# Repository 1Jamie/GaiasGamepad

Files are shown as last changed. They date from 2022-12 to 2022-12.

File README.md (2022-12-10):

# Gaia's Gampad (GGP)
This is most of what is required to make this gamepad from scratch. This gamepad was made with an arduino micro, 3d printed casing, and handmade circuit boards. Maybe at some point i will do a better writeup of this with detailed instructions on how to make your own. But hey... technically everything is here that you need.

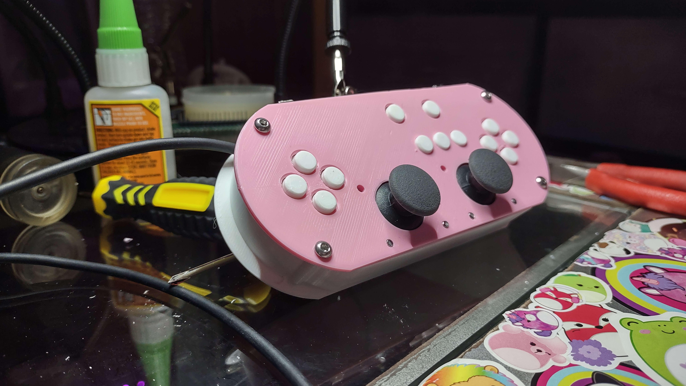
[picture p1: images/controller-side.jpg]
image of controller #2

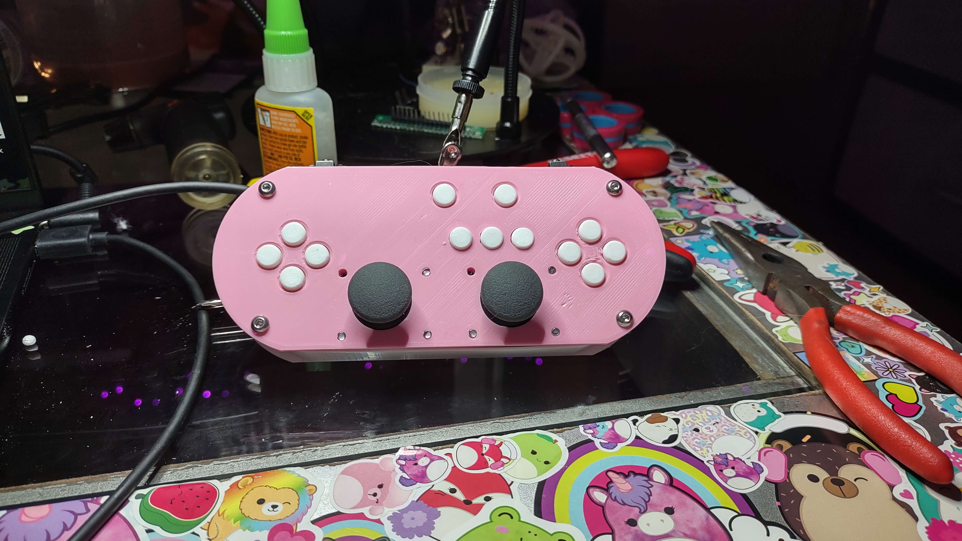
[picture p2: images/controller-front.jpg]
image of controller


## Overview
This controller supports 16 buttons for inputs and one button from swapping mode, current supports mouse input mode and standard HID gamepad input. We are using the gampad library for the micro that can be found in the arduino ide library manager. The buttons themselves are setup using a button matrix scanning through the inputs over and over again every cycle. Also included are the wiring schematics for this gamepad in case you would like to reproduce it or improove it. Please note its only populated with a schematic and not a pcb layout or the like but kiCad auto generates the file for you.

## Parts
- Arduino Micro
- pla casing
- 17 push buttons
- 17 diodes (one per button to prevent ghosting)
- 2 analog sticks with pcb module for them to mount with
- 5 pefboards cut to size
- arduino socket
- m3 screws
- a lot of wire

### more coming eventually
i want a full instruction but dont have the effort right now

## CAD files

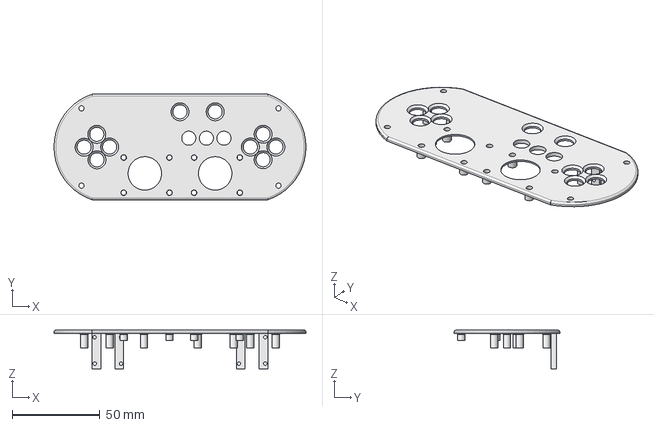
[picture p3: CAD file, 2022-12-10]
ggp-topdeck.FCStd
143.3 x 60.0 x 22.0 mm

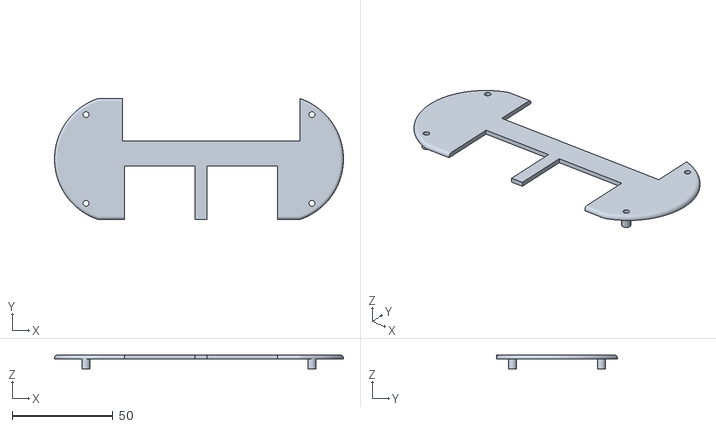
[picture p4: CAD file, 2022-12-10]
stl/ggp-backplate-v1.stl
143.3 x 60.0 x 7.00

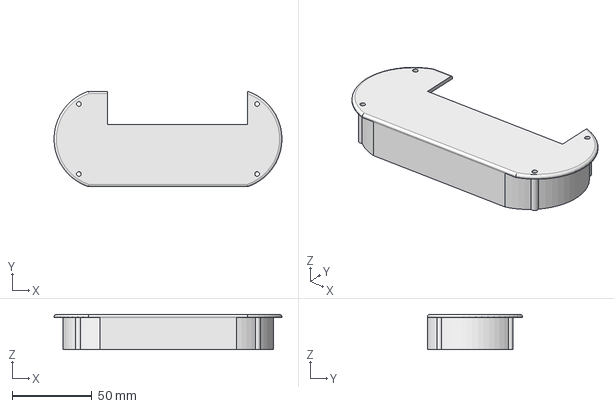
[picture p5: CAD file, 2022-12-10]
ggp-backplate.FCStd
143.3 x 60.0 x 22.0 mm

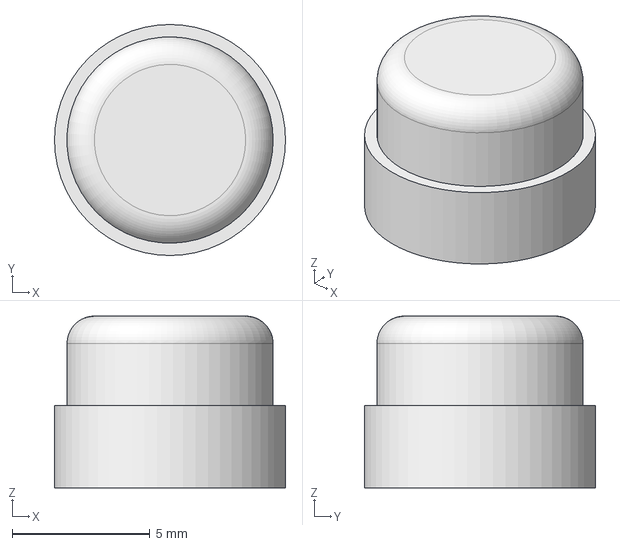
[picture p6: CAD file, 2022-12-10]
ggs-button-caps.FCStd
8.40 x 8.40 x 6.25 mm

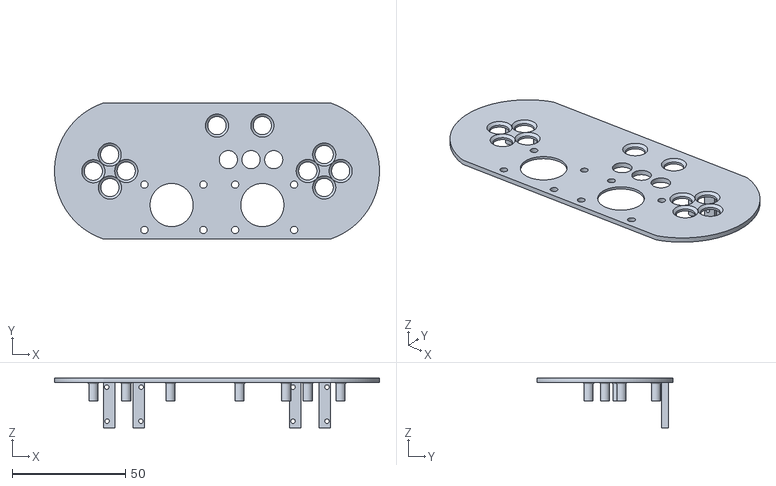
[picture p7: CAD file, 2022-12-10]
stl/ggp-topdeck-v1-3.stl
143.3 x 60.0 x 22.0

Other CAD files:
stl/ggp-topdeck-v1-4.stl
stl/ggp-backplate-v1-1.stl
stl/ggp-button-caps-v1-2.stl

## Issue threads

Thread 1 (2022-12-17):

Enable joystick click

1Jamie, 2022-12-17:
Hardware currently is not wired up for the joystick clicks to work, debating on it as it will take more pins and make analog triggers impossible due to not enough inputs

1Jamie, 2022-12-17:
Also when doing this i need to map the extra center buttons to new things instead of stick clicks.

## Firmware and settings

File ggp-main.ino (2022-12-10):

#include <Joystick.h>
#include <Mouse.h>

// set our pins
int potpinRx = A0;
int potpinRy = A1;
int potpinLx = A2;
int potpinLy = A3;
int modepin = 22;

// set our variables
int mode = 0;
int lastmode = 0;
String pressed;

// setup 4x4 matrix using pins 4-7 and 8-11
char cols[4] = {4, 5, 6, 7};
char rows[4] = {8, 9, 10, 11};
const int colCount = sizeof(cols) / sizeof(cols[0]);
const int rowCount = sizeof(rows) / sizeof(rows[0]);
byte keys[colCount][rowCount];

// function for range mapping
float mapfloat(float x, float in_min, float in_max, float out_min, float out_max)
{
    return (x - in_min) * (out_max - out_min) / (in_max - in_min) + out_min;
}

// setup our joystick
Joystick_ Joystick(JOYSTICK_DEFAULT_REPORT_ID, JOYSTICK_TYPE_GAMEPAD,
                   16, 0,                // Button Count, Hat Switch Count
                   true, true, false,    // X and Y, but no Z Axis
                   true, true, false,    // Rx, Ry, but no Rz
                   false, false,         // No rudder or throttle
                   false, false, false); // No accelerator, brake, or steering

// our setup function
void setup()
{
    // set pin d22 as pullup input
    pinMode(modepin, INPUT_PULLUP);
    // read the mode pin for our initial state
    lastmode = digitalRead(modepin);
    // Initialize Joystick Library
    Joystick.begin();
    Joystick.setXAxisRange(-127, 127);
    Joystick.setYAxisRange(-127, 127);
    Joystick.setRxAxisRange(-127, 127);
    Joystick.setRyAxisRange(-127, 127);

    // initialize the matrix
    for (int i = 0; i < colCount; i++)
    {
        pinMode(cols[i], OUTPUT);
        digitalWrite(cols[i], HIGH);
        Serial.print(cols[i]);
        Serial.print(" ");
    }
    Serial.println();
    for (int i = 0; i < rowCount; i++)
    {
        pinMode(rows[i], INPUT_PULLUP);
        Serial.print(rows[i]);
        Serial.print(" ");
    }
}

// our function to read the matrix
void readMatrix()
{
    // iterate the columns
    for (int colIndex = 0; colIndex < colCount; colIndex++)
    {
        // col: set to output to low
        byte curCol = cols[colIndex];
        pinMode(curCol, OUTPUT);
        digitalWrite(curCol, LOW);

        // row: interate through the rows
        for (int rowIndex = 0; rowIndex < rowCount; rowIndex++)
        {
            byte rowCol = rows[rowIndex];
            pinMode(rowCol, INPUT_PULLUP);
            keys[colIndex][rowIndex] = !digitalRead(rowCol);
            pinMode(rowCol, INPUT);
        }
        // disable the column
        pinMode(curCol, INPUT);
    }
}

// Last state of the buttons
int lastButtonState[16] = {0, 0, 0, 0, 0, 0, 0, 0, 0, 0, 0, 0, 0, 0, 0, 0};

// our main loop
void loop()
{
    // Read the mode pin
    int tmpmode = digitalRead(modepin);
    // if the mode pin has changed then change the mode from 0 to 1 or 1 to 0
    if (tmpmode != lastmode && tmpmode == 0)
    {
        mode = !mode;
        Serial.println(mode);
        lastmode = tmpmode;
        // start up the mouse if 1 and stop it if 0
        if (mode == 1)
        {
            Mouse.begin();
        }
        else if (mode == 0)
        {
            Mouse.end();
        }
    }
    else
    {
        lastmode = tmpmode;
    }

    // use the readMatrix function to read the matrix
    readMatrix();

    // check which mode we are in
    if (mode == 0)
    {
        // Read pin values, map them to the proper range
        int potMappedRx = mapfloat(analogRead(potpinRx), 0, 1023, -127, 127);
        int potMappedRy = mapfloat(analogRead(potpinRy), 0, 1023, -127, 127);
        int potMappedLx = mapfloat(analogRead(potpinLx), 0, 1023, -127, 127);
        int potMappedLy = mapfloat(analogRead(potpinLy), 0, 1023, -127, 127);
        // send the joystick values to the computer
        Joystick.setXAxis(potMappedLx);
        Joystick.setYAxis(potMappedLy);
        Joystick.setRxAxis(potMappedRx);
        Joystick.setRyAxis(potMappedRy);

        // read through keys array by row and see if any buttons have changed state
        for (int i = 0; i < rowCount; i++)
        {
            for (int j = 0; j < colCount; j++)
            {
                int buttonIndex = i * colCount + j;
                int buttonState = keys[j][i];
                // if the button state has changed then send the button press to the computer
                if (buttonState != lastButtonState[buttonIndex])
                {
                    Serial.print("keys[");
                    Serial.print(j);
                    Serial.print("][");
                    Serial.print(i);
                    Serial.print("] ");
                    Serial.print("Button ");
                    Serial.print(buttonIndex);
                    Serial.print(" ");
                    Serial.println(buttonState);
                    if (buttonState == 1)
                    {
                        Joystick.pressButton(buttonIndex);
                    }
                    else
                    {
                        Joystick.releaseButton(buttonIndex);
                    }
                    lastButtonState[buttonIndex] = buttonState;
                }
            }
        }
    }
    else if (mode == 1)
    {
        // map potmapped values to between -1 and 1
        float potMappedRy = mapfloat(analogRead(potpinRy), 0, 1023, -10, 10);
        float potMappedLx = mapfloat(analogRead(potpinLx), 0, 1023, -20, 20);
        float potMappedLy = mapfloat(analogRead(potpinLy), 0, 1023, -20, 20);
        Serial.print("ly: ");
        Serial.print(potMappedLy);
        Serial.print(" lx: ");
        Serial.print(potMappedLx);
        Serial.print(" ry: ");
        Serial.println(potMappedRy);

        // move the mouse
        Mouse.move(potMappedLx, potMappedLy, potMappedRy);
        // deal with clicks
        if (keys[0][0] == 1) // left click
        {
            Mouse.press(MOUSE_LEFT);
        }
        else
        {
            Mouse.release(MOUSE_LEFT);
        }
        if (keys[2][0] == 1) // right click
        {
            Mouse.press(MOUSE_RIGHT);
        }
        else
        {
            Mouse.release(MOUSE_RIGHT);
        }
        if (keys[3][0] == 1) // middle click
        {
            Mouse.press(MOUSE_MIDDLE);
        }
        else
        {
            Mouse.release(MOUSE_MIDDLE);
        }
        // delay for 50ms
        delay(25);
    }
}
